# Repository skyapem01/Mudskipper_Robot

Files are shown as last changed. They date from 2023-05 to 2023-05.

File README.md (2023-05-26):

# Mudskipper_Robot
  หุ่นยนต์จำลองการเคลื่อนที่ของปลาตีน โดยจำลองตัวปลาตีน ครีบอก หาง 

## Mudskipper Robot Model
  การใช้งาน ในโฟลเดอร์ Mudskipper_Solid2022 มีไฟล์ Part และไฟล์ Assembly ซึ่งเป็น Model 3D ของตัวหุ่นยนต์ ไฟล์ให้งานกับ SolidWork ver.2022
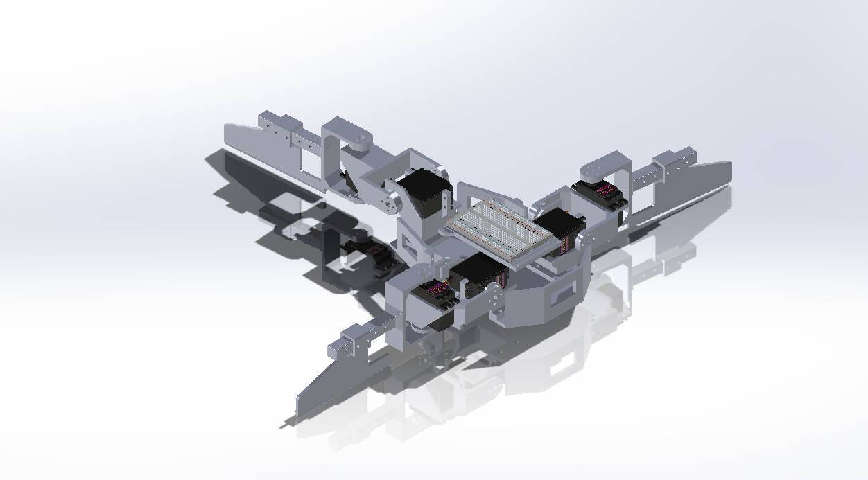
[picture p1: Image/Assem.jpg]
  

## Programing 
  ในโฟลเดอร์ Mudskipper_code มีไฟล์โปรแกรมการใช้งานหุ่นยนต์ โดยรวมโปรแกรมนี้ ใช้สมการ central pattern generators ในการสั่งงาน Servomoter ดังนั้นให้ศึกษา central pattern generators ก่อนทำความเข้าใจ code และใช้งาน code
  ### central pattern generators
  ประสาทชีวภาพที่จัดระเบียบตัวเองวงจรที่สร้างจังหวะเอาต์พุตในกรณีที่ไม่มีจังหวะป้อนข้อมูล. เป็นที่มาของรูปแบบของเส้นประสาทที่เชื่อมต่อกัน
 ที่ขับเคลื่อนจังหวะและพฤติกรรมของมอเตอร์ตายตัว
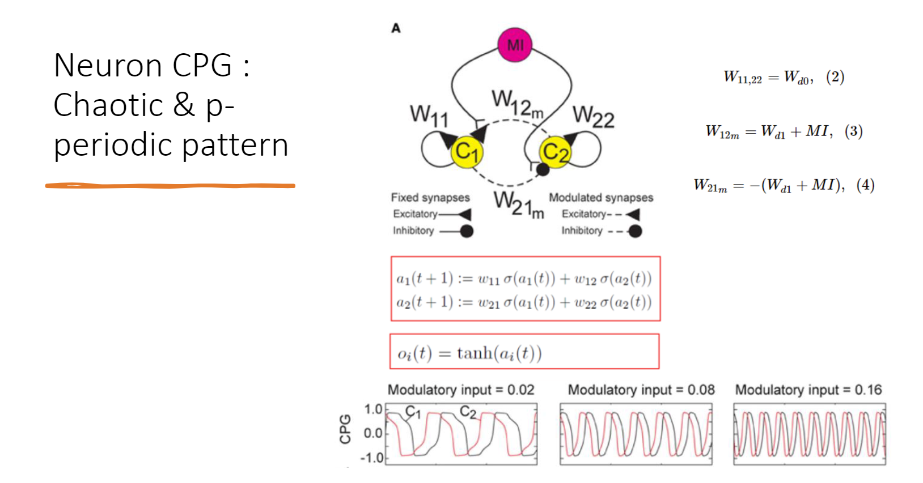
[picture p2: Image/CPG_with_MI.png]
  

 ## Document
  ในโฟลเดอร์ Mudskipper_Document มีไฟล์ Document อธิบายเกี่ยวกับ Mudskipper ทั้งหมด เช่น Circuit, Hardware , การทดลอง 
  ### Presenttation
  [Presentation](https://www.canva.com/design/DAFkBGQHBKI/dXqKwkPjZiT8uN1swqLo2Q/view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)

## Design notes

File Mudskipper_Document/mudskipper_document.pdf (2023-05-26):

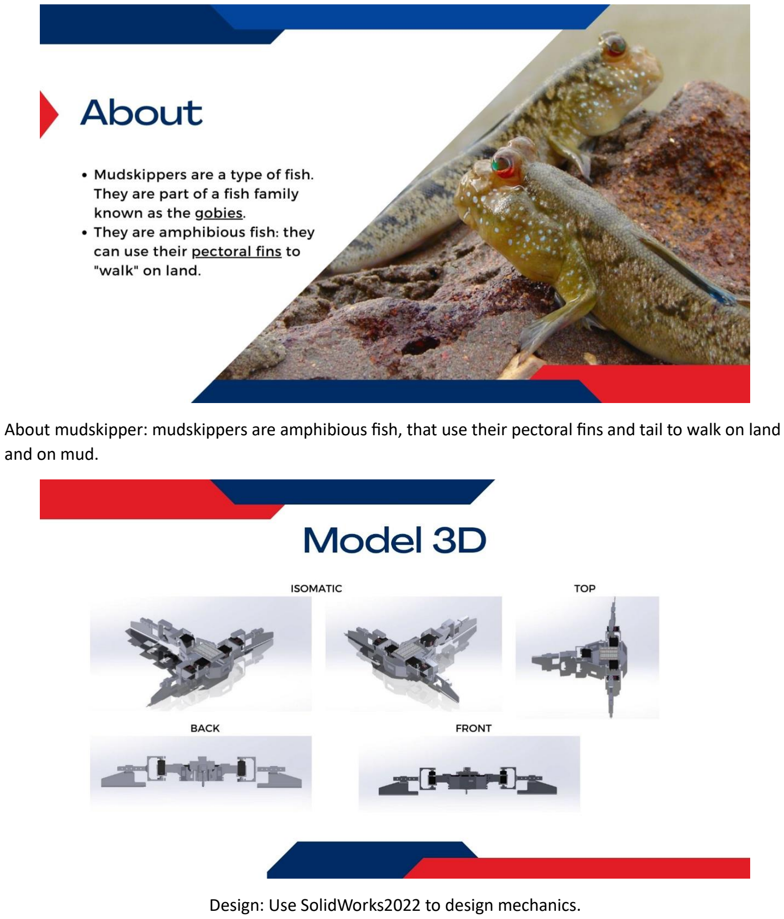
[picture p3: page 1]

About mudskipper: mudskippers are amphibious fish, that use their pectoral fins and tail to walk on land and on mud.

Design: Use SolidWorks2022 to design mechanics.

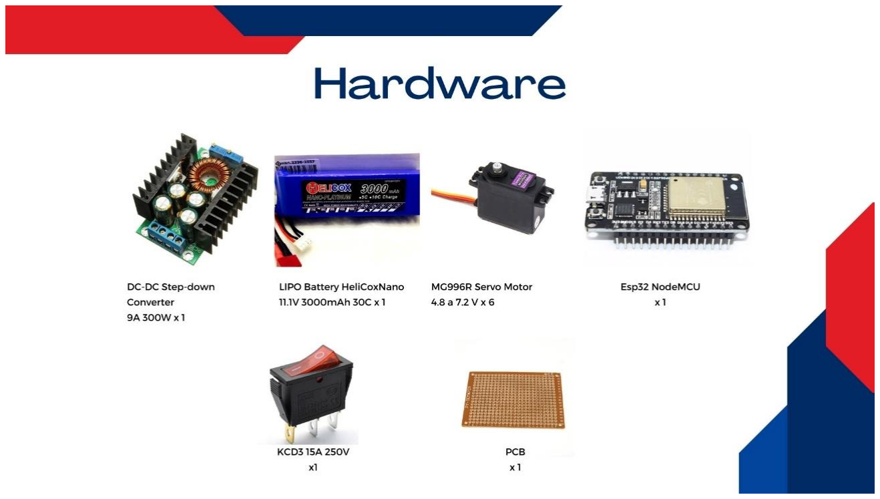
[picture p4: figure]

Hardware:

Part name | Qty.
LIPO Battery HeliCox Nano | 1
KCD3 Rocker Switch | 1
DC-DC Step Down Buck Converter | 1
ESP-WROOM-32 | 1
MG996R Servo motor | 6

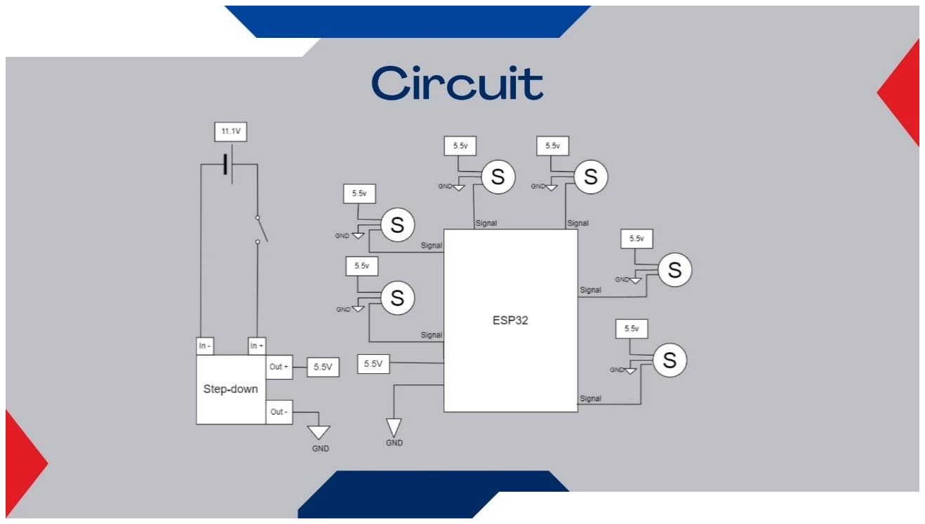
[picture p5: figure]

Circuit diagram: Power the ESP32 and servo motor with the LIPO Battery HeliCox Nano.

Step 1: As a circuit diagram, connect a switch to a LIPO Battery to power the ESP32 and servo motor.
Step 2: Use a DC-DC Step Down Buck Converter to reduce the current from the LIPO Battery HeliCox Nano to 7.2A and the voltage to 5.5V.
Step 3: Connect a signal and the GND of the servo motor to the ESP32, then connect to step 1 as shown.

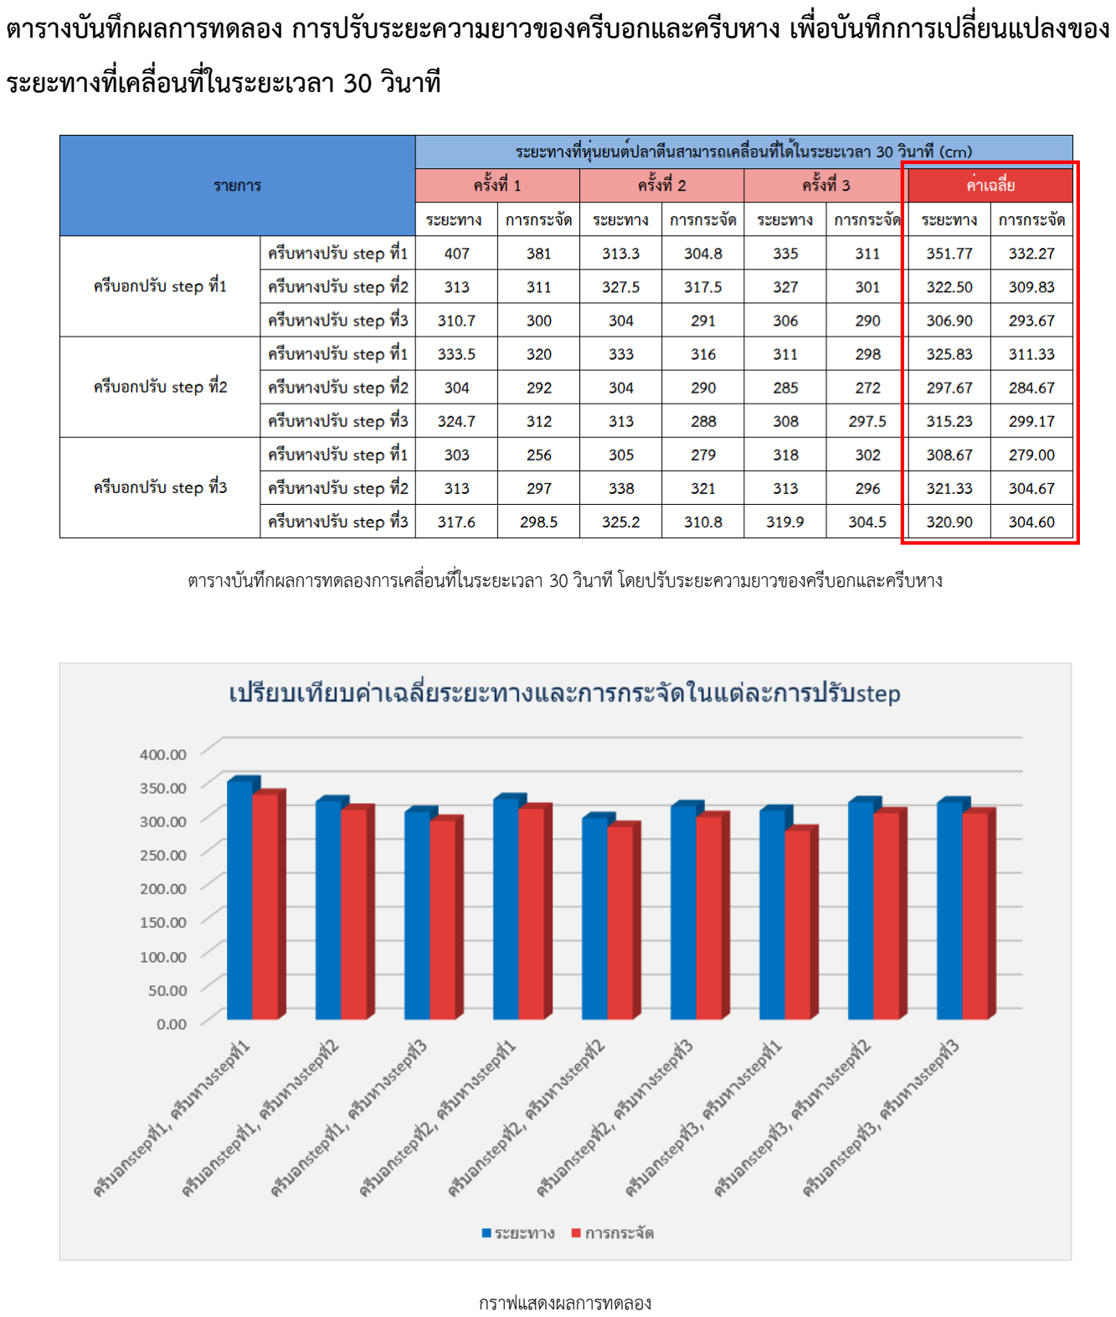
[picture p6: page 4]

ตารางบันทึกผลการทดลอง การปรับระยะความยาวของครีบอกและครีบหาง เพื่อบันทึกการเปลี่ยนแปลงของ ระยะทางที่เคลื่อนที่ในระยะเวลา 30 วินาที

ตารางบันทึกผลการทดลองการเคลื่อนที่ในระยะเวลา 30 วินาที โดยปรับระยะความยาวของครีบอกและครีบหาง

กราฟแสดงผลการทดลอง

อภิปรายผลการทดลอง

เมื่อครีบอกอยู่ระดับที่1:

ครีบหางระดับที่1 ระยะทางเฉลี่ยเท่ากับ 351.77 เซนติเมตร การกระจัดเฉลี่ยเท่ากับ 332.27 เซนติเมตร ครีบหางระดับที่2 ระยะทางเฉลี่ยเท่ากับ 322.50 เซนติเมตร การกระจัดเฉลี่ยเท่ากับ 309.83 เซนติเมตร ครีบหางระดับที่3 ระยะทางเฉลี่ยเท่ากับ 306.90 เซนติเมตร การกระจัดเฉลี่ยเท่ากับ 293.67 เซนติเมตร

เมื่อครีบอกอยู่ระดับที่2:

ครีบหางระดับที่1ระยะทางเฉลี่ยเท่ากับ 325.83 เซนติเมตร การกระจัดเฉลี่ยเท่ากับ 311.33 เซนติเมตร ครีบหางระดับที่2 ระยะทางเฉลี่ยเท่ากับ 297.67 เซนติเมตร การกระจัดเฉลี่ยเท่ากับ 284.67 เซนติเมตร ครีบหางระดับที่3 ระยะทางเฉลี่ยเท่ากับ 315.23 เซนติเมตร การกระจัดเฉลี่ยเท่ากับ 299.17 เซนติเมตร

เมื่อครีบอกอยู่ระดับที่3:

ครีบหางระดับที่1 ระยะทางเฉลี่ยเท่ากับ 308.67 เซนติเมตร การกระจัดเฉลี่ยเท่ากับ 279.00 เซนติเมตร ครีบหางระดับที่2 ระยะทางเฉลี่ยเท่ากับ 321.33 เซนติเมตร การกระจัดเฉลี่ยเท่ากับ 304.67 เซนติเมตร ครีบหางระดับที่3 ระยะทางเฉลี่ยเท่ากับ 320.90 เซนติเมตร การกระจัดเฉลี่ยเท่ากับ 304.60 เซนติเมตร

สรุปผลการทดลอง

จากข้อมูลข้างต้นแสดงให้เห็นว่าการปรับระยะความยาวของครีบอกและครีบหาง มีผลต่อระยะทางที่เคลื่อนที่ใน ระยะเวลา 30 วินาที โดยระยะทางที่เคลื่อนที่ได้จะมีค่าต่างกัน ตามการปรับระยะความยาวของครีบในแต่ละครั้ง และจากการ ทดลองสรุปผลได้ว่าในเวลาที่ 30 วินาทีเท่ากัน ระยะทางเฉลี่ยที่มากที่สุด คือ ครีบอกอยู่ระดับที่1 และครีบหางระดับที่1

ตารางบันทึกผลการทดลองการเปรียบเทียบลักษณะการเคลื่อนที่เข้าสู่จุดหมาย โดยการวัดค่า Displacement

แบ่งเป็น 4 การทดลอง

โดยการหาค่า Displacement Index อ้างอิงจากสูตร

สูตร

∆x คือ ระยะที่กำหนด

∆s คือ Pathway ที่หุ่นยนต์เดินทางได้

|| ∆r || = √x
2 + y

2

Displacement Index คือ ดัชนีวัดประสิทธิภาพในการเคลื่อนที่ของ หุ่นยนต์

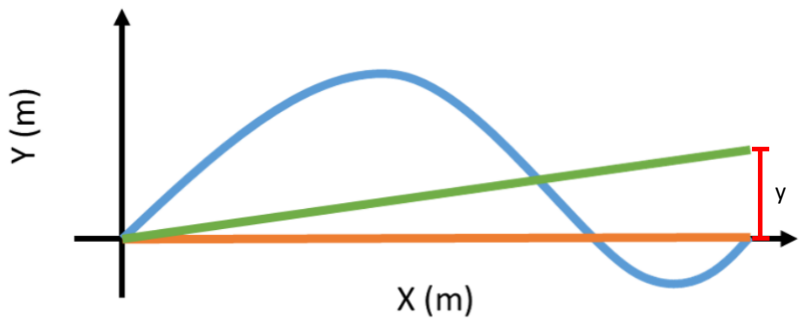
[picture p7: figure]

### 1. หาค่า displacement แบบเคลื่อนที่โดยไม่ใช้หาง ในระยะทางที่กำหนดเท่ากับ 100 cm

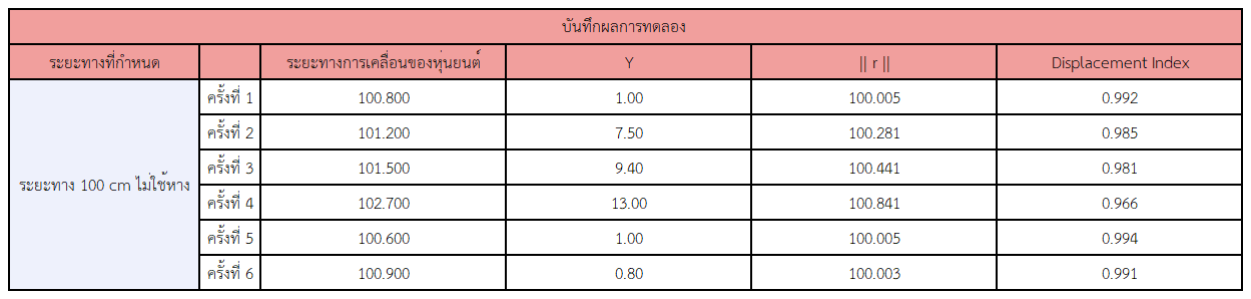
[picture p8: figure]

ตารางบันทึกผลการทดลองหาค่า displacement แบบเคลื่อนที่โดยไม่ใช้หาง และระยะทางที่กำหนดเท่ากับ 100 cm

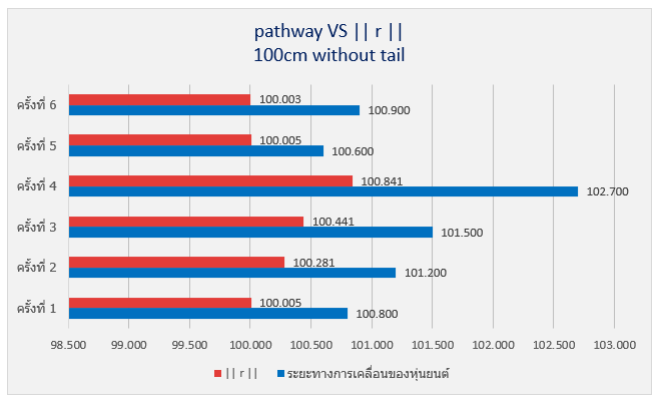
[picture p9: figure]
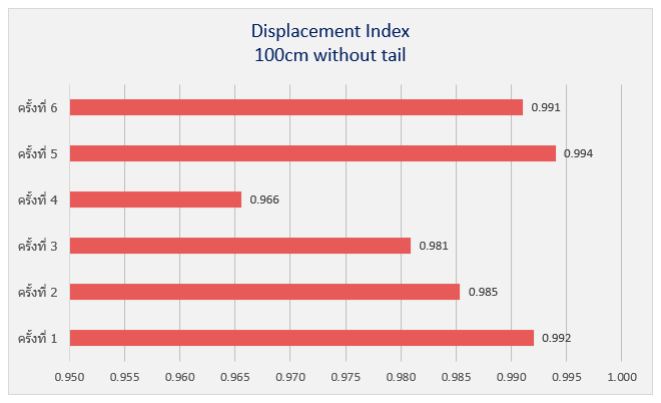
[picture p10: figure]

กราฟแสดงผล

อภิปรายผลการทดลอง : หาค่า displacement แบบเคลื่อนที่โดยไม่ใช้หาง ในระยะทางที่กำหนดเท่ากับ 100 cm

การทดลองครั้งที่ 1 : ระยะทางที่หุ่นยนต์เคลื่อนที่ = 100.80 cm, ค่า || r || = 100.005 cm, และค่า Displacement คือ 0.992

การทดลองครั้งที่ 2 : ระยะทางที่หุ่นยนต์เคลื่อนที่ = 101.20 cm, ค่า || r || = 100.218 cm, และค่า Displacement คือ 0.985

การทดลองครั้งที่ 3 : ระยะทางที่หุ่นยนต์เคลื่อนที่ = 101.50 cm, ค่า || r || = 100.441 cm, และค่า Displacement คือ 0.981

การทดลองครั้งที่ 4 : ระยะทางที่หุ่นยนต์เคลื่อนที่ = 102.70 cm, ค่า || r || = 100.841 cm, และค่า Displacement คือ 0.966

การทดลองครั้งที่ 5 : ระยะทางที่หุ่นยนต์เคลื่อนที่ = 100.60 cm, ค่า || r || = 100.005 cm, และค่า Displacement คือ 0.994

การทดลองครั้งที่ 6 : ระยะทางที่หุ่นยนต์เคลื่อนที่ = 100.90 cm, ค่า || r || = 100.003 cm, และค่า Displacement คือ 0.991

### 2. หาค่า displacement แบบเคลื่อนที่โดยใช้หาง และระยะทางที่กำหนดเท่ากับ 100 cm

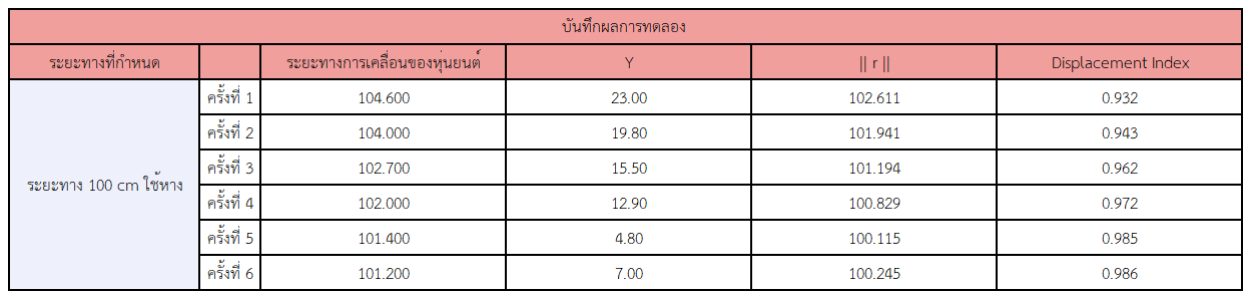
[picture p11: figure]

ตารางบันทึกผลการทดลองหาค่า displacement แบบเคลื่อนที่โดยใช้หาง และระยะทางที่กำหนดเท่ากับ 100 cm

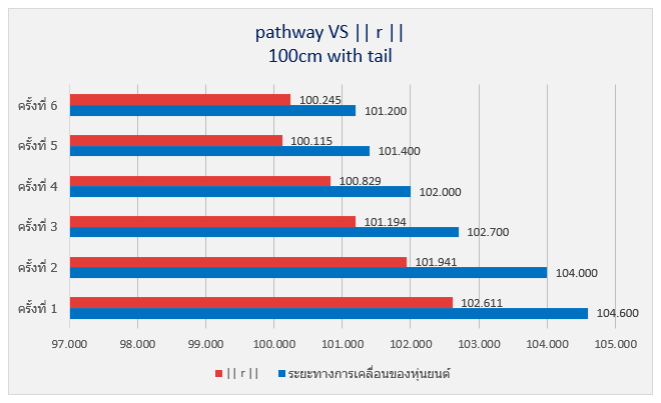
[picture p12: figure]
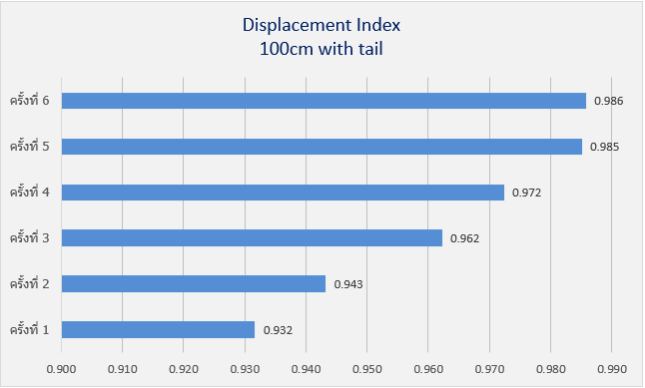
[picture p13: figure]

กราฟแสดงผล

อภิปรายผลการทดลอง : หาค่า displacement แบบเคลื่อนที่โดยใช้หาง ในระยะทางที่กำหนดเท่ากับ 100 cm

การทดลองครั้งที่ 1 : ระยะทางที่หุ่นยนต์เคลื่อนที่ = 104.60 cm, ค่า || r || = 102.611 cm, และค่า Displacement คือ 0.932

การทดลองครั้งที่ 2 : ระยะทางที่หุ่นยนต์เคลื่อนที่ = 104.00 cm, ค่า || r || = 101.941 cm, และค่า Displacement คือ 0.943

การทดลองครั้งที่ 3 : ระยะทางที่หุ่นยนต์เคลื่อนที่ = 102.70 cm, ค่า || r || = 101.194 cm, และค่า Displacement คือ 0.962

การทดลองครั้งที่ 4 : ระยะทางที่หุ่นยนต์เคลื่อนที่ = 102.00 cm, ค่า || r || = 100.829 cm, และค่า Displacement คือ 0.972

การทดลองครั้งที่ 5 : ระยะทางที่หุ่นยนต์เคลื่อนที่ = 101.40 cm, ค่า || r || = 100.115 cm, และค่า Displacement คือ 0.985

การทดลองครั้งที่ 6 : ระยะทางที่หุ่นยนต์เคลื่อนที่ = 101.20 cm, ค่า || r || = 100.245 cm, และค่า Displacement คือ 0.986

สรุปผลการทดลอง

จากการทดลองหาค่า displacement แบบเคลื่อนที่โดยใช้หาง ในระยะทาง 100 cm เห็นได้ว่าระยะทางที่หุ่นยนต์ เคลื่อนที่ (Pathway) และค่า || r || ที่คำนวณได้ในแต่ละครั้งของการทดลองมีค่าความห่างกันมากสุด 1.859 cm และค่า displacement คือ 0.966 ในขณะที่การทดลองที่มีค่าความห่างกันน้อยที่สุดประมาณ 0.595 cm และค่า displacement คือ 0.994

เมื่อเปรียบเทียบกับการทดลองหาค่า displacement แบบเคลื่อนที่โดยใช้หาง ในระยะทาง 100 cm เท่ากัน ระยะทางที่ หุ่นยนต์เคลื่อนที่ (Pathway) และค่า || r || ที่คำนวณได้ในแต่ละครั้งของการทดลองมีค่าความห่างกันมากสุด 2.059 cm และค่า displacement คือ 0.932 ในขณะที่การทดลองที่มีค่าความห่างกันน้อยที่สุดประมาณ 0.955 cm และค่า displacement คือ 0.986

### 3. หาค่า displacement แบบเคลื่อนที่โดยไม่ใช้หาง และระยะทางที่กำหนดเท่ากับ 200 cm

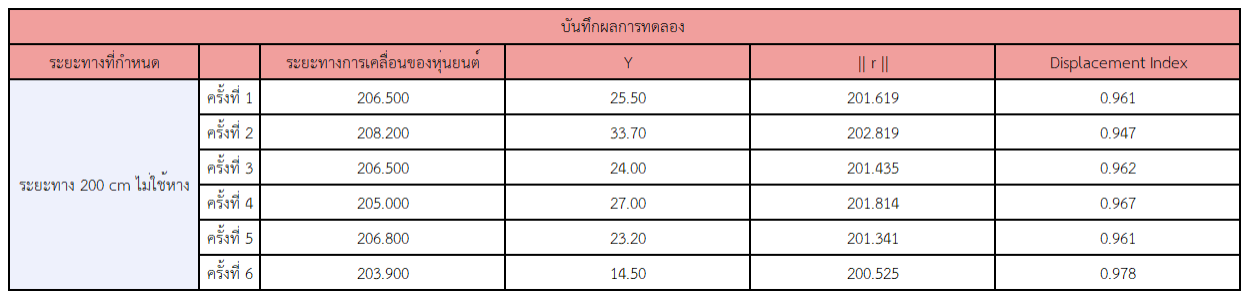
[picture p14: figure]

ตารางบันทึกผลการทดลองหาค่า displacement แบบเคลื่อนที่โดยไม่ใช้หาง และระยะทางที่กำหนดเท่ากับ 200 cm

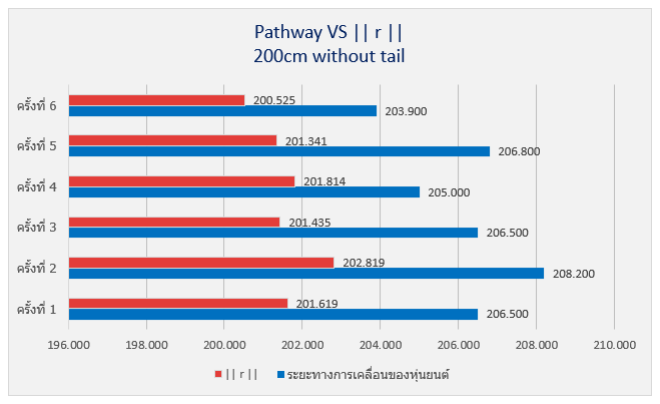
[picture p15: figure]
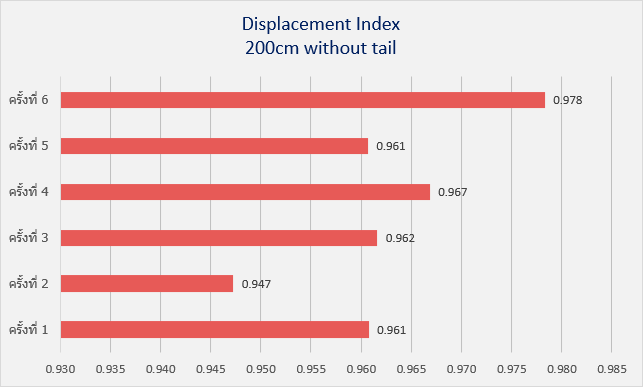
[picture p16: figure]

กราฟแสดงผล

อภิปรายผลการทดลอง : หาค่า displacement แบบเคลื่อนที่โดยไม่ใช้หาง ในระยะทางที่กำหนดเท่ากับ 200 cm

การทดลองครั้งที่ 1 : ระยะทางที่หุ่นยนต์เคลื่อนที่ = 206.50 cm, ค่า || r || = 201.619 cm, และค่า Displacement คือ 0.961

การทดลองครั้งที่ 2 : ระยะทางที่หุ่นยนต์เคลื่อนที่ = 208.20 cm, ค่า || r || = 202.819 cm, และค่า Displacement คือ 0.947

การทดลองครั้งที่ 3 : ระยะทางที่หุ่นยนต์เคลื่อนที่ = 206.50 cm, ค่า || r || = 201.435 cm, และค่า Displacement คือ 0.962

การทดลองครั้งที่ 4 : ระยะทางที่หุ่นยนต์เคลื่อนที่ = 205.00 cm, ค่า || r || = 201.814 cm, และค่า Displacement คือ 0.967

การทดลองครั้งที่ 5 : ระยะทางที่หุ่นยนต์เคลื่อนที่ = 206.80 cm, ค่า || r || = 201.341 cm, และค่า Displacement คือ 0.961

การทดลองครั้งที่ 6 : ระยะทางที่หุ่นยนต์เคลื่อนที่ = 203.90 cm, ค่า || r || = 200.525 cm, และค่า Displacement คือ 0.978

### 4. หาค่า displacement แบบเคลื่อนที่โดยใช้หาง และระยะทางที่กำหนดเท่ากับ 200 cm

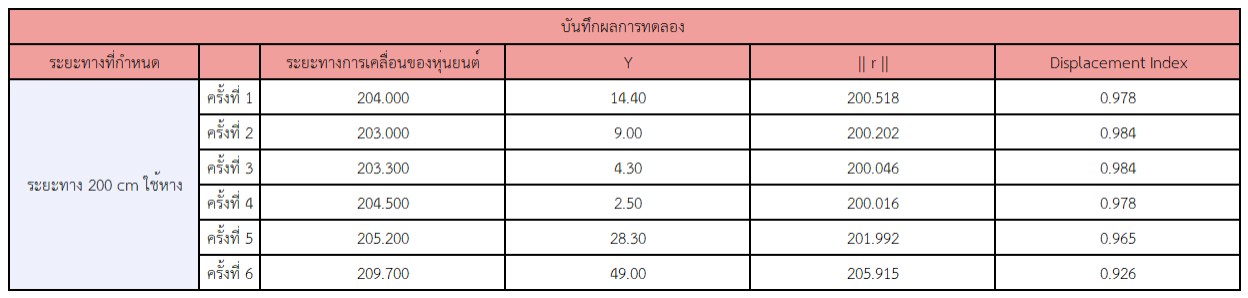
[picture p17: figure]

ตารางบันทึกผลการทดลองหาค่า displacement แบบเคลื่อนที่โดยใช้หาง และระยะทางที่กำหนดเท่ากับ 200 cm

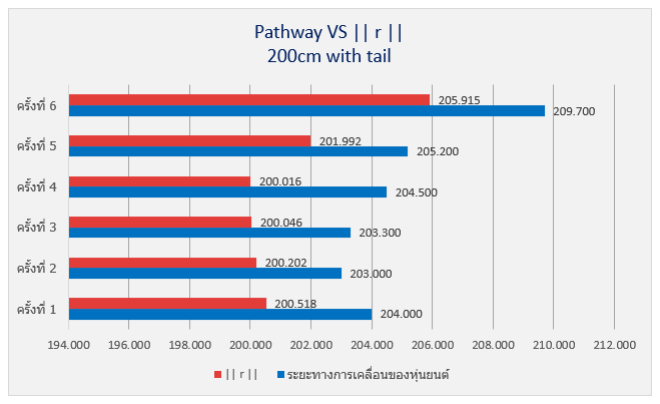
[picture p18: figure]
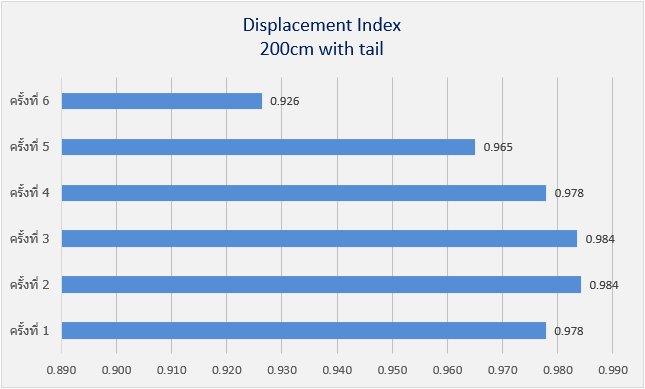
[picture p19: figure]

กราฟแสดงผล

อภิปรายผลการทดลอง : หาค่า displacement แบบเคลื่อนที่โดยใช้หาง ในระยะทางที่กำหนดเท่ากับ 200 cm

การทดลองครั้งที่ 1 : ระยะทางที่หุ่นยนต์เคลื่อนที่ = 204.00 cm, ค่า || r || = 200.518 cm, และค่า Displacement คือ 0.978

การทดลองครั้งที่ 2 : ระยะทางที่หุ่นยนต์เคลื่อนที่ = 203.00 cm, ค่า || r || = 200.202 cm, และค่า Displacement คือ 0.984

การทดลองครั้งที่ 3 : ระยะทางที่หุ่นยนต์เคลื่อนที่ = 203.30 cm, ค่า || r || = 200.046 cm, และค่า Displacement คือ 0.984

การทดลองครั้งที่ 4 : ระยะทางที่หุ่นยนต์เคลื่อนที่ = 204.50 cm, ค่า || r || = 200.016 cm, และค่า Displacement คือ 0.978

การทดลองครั้งที่ 5 : ระยะทางที่หุ่นยนต์เคลื่อนที่ = 205.20 cm, ค่า || r || = 201.992 cm, และค่า Displacement คือ 0.965

การทดลองครั้งที่ 6 : ระยะทางที่หุ่นยนต์เคลื่อนที่ = 209.70 cm, ค่า || r || = 205.915 cm, และค่า Displacement คือ 0.926

สรุปผลการทดลอง

จากการทดลองหาค่า displacement แบบเคลื่อนที่โดยไม่ใช้หาง ในระยะทาง 200 cm เห็นได้ว่าระยะทางที่หุ่นยนต์ เคลื่อนที่ (Pathway) และค่า || r || ที่คำนวณได้ในแต่ละครั้งของการทดลองมีค่าความห่างกันมากสุด 1.859 cm และค่า displacement คือ 0.966 ในขณะที่การทดลองที่มีค่าความห่างกันน้อยที่สุดประมาณ 0.595 cm และค่า displacement คือ 0.994

เมื่อเปรียบเทียบกับการทดลองหาค่า displacement แบบเคลื่อนที่โดยใช้หาง ในระยะทาง 200 cm เท่ากัน ระยะทางที่ หุ่นยนต์เคลื่อนที่ (Pathway) และค่า || r || ที่คำนวณได้ในแต่ละครั้งของการทดลองมีค่าความห่างกันมากสุด 3.785 cm และค่า displacement คือ 0.926 ในขณะที่การทดลองที่มีค่าความห่างกันน้อยที่สุดประมาณ 2.798 cm และค่า displacement คือ 0.984

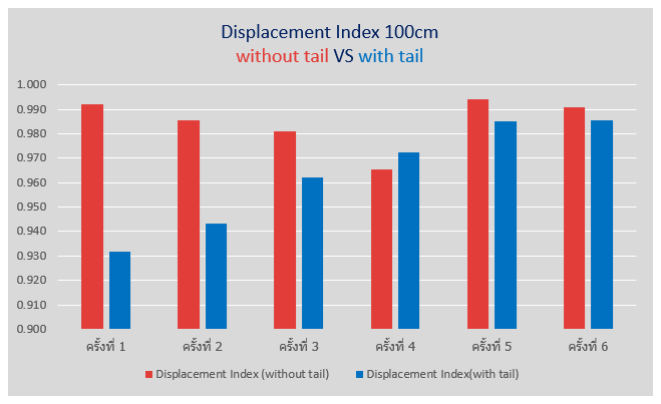
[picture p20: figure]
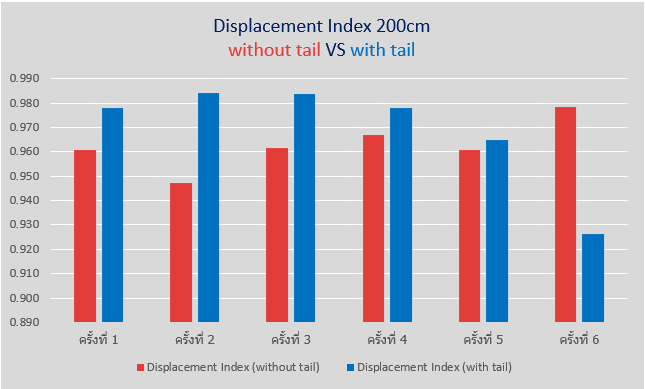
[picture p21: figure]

กราฟเปรียบเทียบค่า displacement ระหว่างใช้หางและไม่ใช้หางในระยะ 100 cm และ 200 cm

จากกราฟ การเปรียบเทียบ Displacement Index ของการเคลื่อนที่ 100 cm การเคลื่อนที่ไม่ใช้หางมีค่า Displacement Index ที่ดีกว่าการเคลื่อนที่ที่ใช้หางช่วย ในการกราฟการเทียบเทียบ Displacement Index ของการเคลื่อนที่ 200 cm การเคลื่อนที่ที่ใช้หางช่วยมีค่า Displacement Index ที่ดีกว่าการเคลื่อนที่ที่ไม่ใช้หาง

ปัญหาที่พบ :

การเปลี่ยนระดับครีบหางและครีบอก

จากผลการสรุปการทดลองการเปลี่ยนระดับครีบหางและครีบอก ตามทฤษฎีแล้ว ถ้าเพิ่มระยะของครีบอกหรือครีบหาง จะทำให้ระยะการเคลื่อนเพิ่มขึ้น เนื่องจากพื้นที่หน้าสัมผัสกับพื้นมากขึ้น แต่จากการทดลองไม่เป็นไปตามทฤษฎีอาจเป็นเพราะมี ปัจจัยอื่นมาเกี่ยวข้องในการเคลื่อนที่ เช่น พื้นผิวในการทดสอบ, สมดุลของหุ่นขณะเคลื่อนที่เมื่อขยายครีบ, แรงกระแทกกับพื้นเมื่อ หุ่นเคลื่อนที่ ทำให้ทิศทางการเคลื่อนที่เปลี่ยนแปลงจากเดิม

การวัดค่า Displacement

จากการทดลองการวัดค่า Displacement ในระยะ 100 cm และ 200 cm วิธีการบันทึกระยะทางการเคลื่อนที่ของ หุ่นยนต์ไม่เสถียร

ข้อเสนอแนะ :

การเปลี่ยนระดับครีบหางและครีบอก

1.ควรเพิ่มตัวแปรควบคุมในการทดลอง เช่น ชนิดพื้นผิวในการทดลองให้มีความหลากหลายมากขึ้น

2.ควรทดลองเปลี่ยนวัสดุที่ทำครีบเพื่อการเคลื่อนที่ที่ดีขึ้น โดยมีแรงบันดาลจากปลาตีนมากขึ้นอีก

3.เพิ่มเซ็นเซอร์ในการรับรู้สภาพแวดล้อม เพื่อให้การเคลื่อนที่มีประสิทธิภาพมากขึ้น

การวัดค่า Displacement

1.ควรมีวิธีการในการบันทึกการเคลื่อนที่ของหุ่นยนต์ที่ไม่ส่งผลต่อการเคลื่อนที่ของหุ่นยนต์เอง

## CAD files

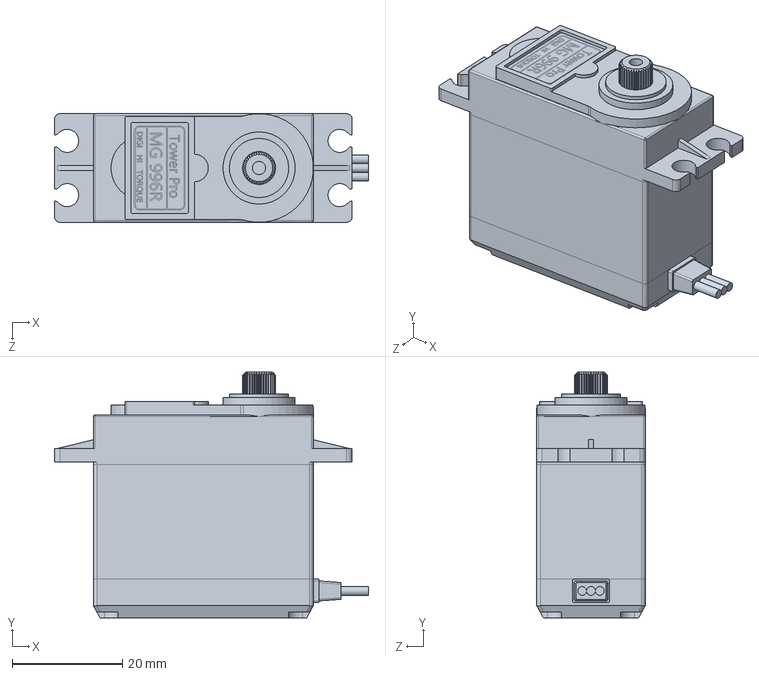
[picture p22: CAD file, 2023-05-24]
Mudskipper_Solid2022/Mudskipper_Solid2022/Servo Motor MG996R With Attachments.SLDASM
57.0 x 44.5 x 19.7 mm

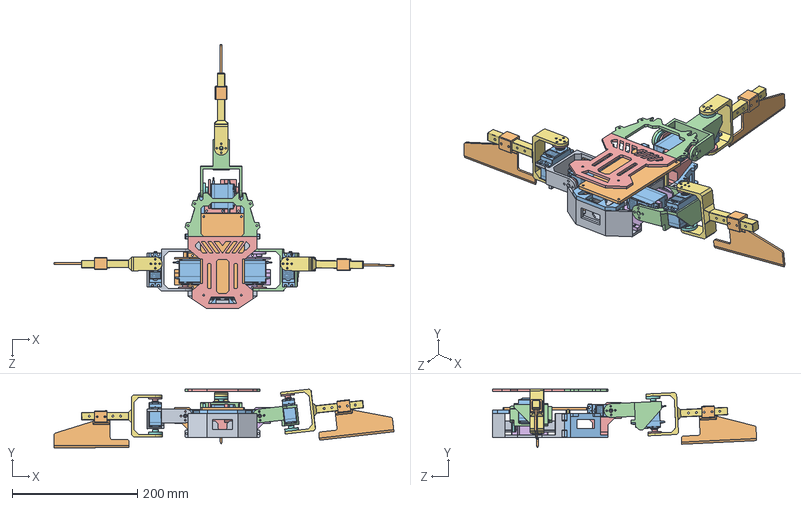
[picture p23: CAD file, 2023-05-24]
Mudskipper_Solid2022/Mudskipper_Solid2022/Assem4.SLDASM
542.7 x 93.9 x 421.9 mm
Plate_final
Plate_Right
Servo Motor MG996R x 6
ติดก้าน
circleServo_6m x 6
circle_7m
ติดก้านหาง - Copy x 3
circle_6m x 4
ติดก้าน - Copy (2)
Foot x 3
Plate_Back1
ติดก้านหาง
Plate_1Back
Plate_Left
Stud_41m x 2
Stud_41m - Copy x 2
Batterry_Base
switch

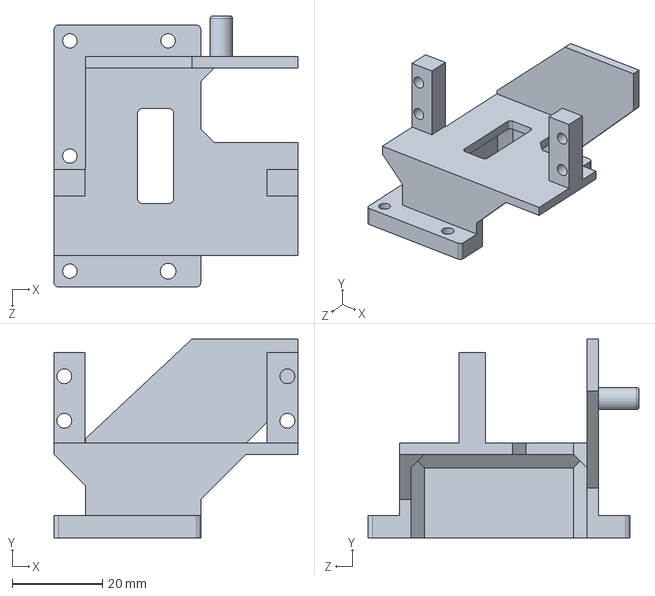
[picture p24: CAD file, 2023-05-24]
Mudskipper_Solid2022/Mudskipper_Solid2022/Plate_Left.SLDPRT
54.0 x 44.0 x 60.0 mm

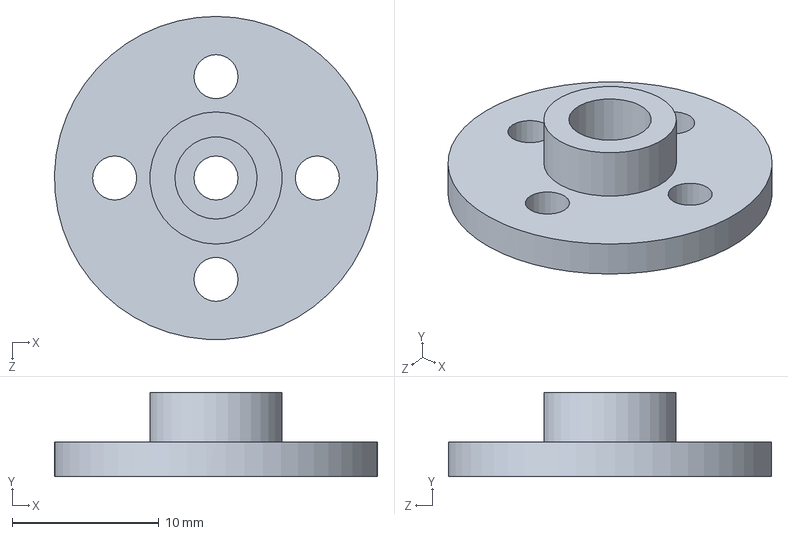
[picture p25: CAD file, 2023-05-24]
Mudskipper_Solid2022/Mudskipper_Solid2022/circleServo_6m.SLDPRT
22.0 x 5.75 x 22.0 mm

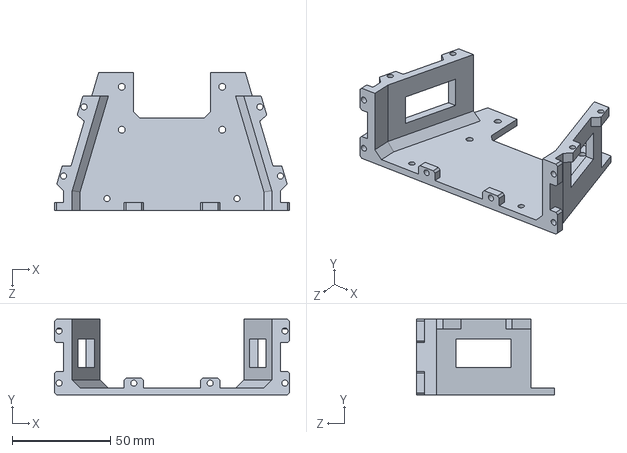
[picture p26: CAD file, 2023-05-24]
Mudskipper_Solid2022/Mudskipper_Solid2022/Plate_Back1.SLDPRT
119.3 x 38.5 x 70.0 mm

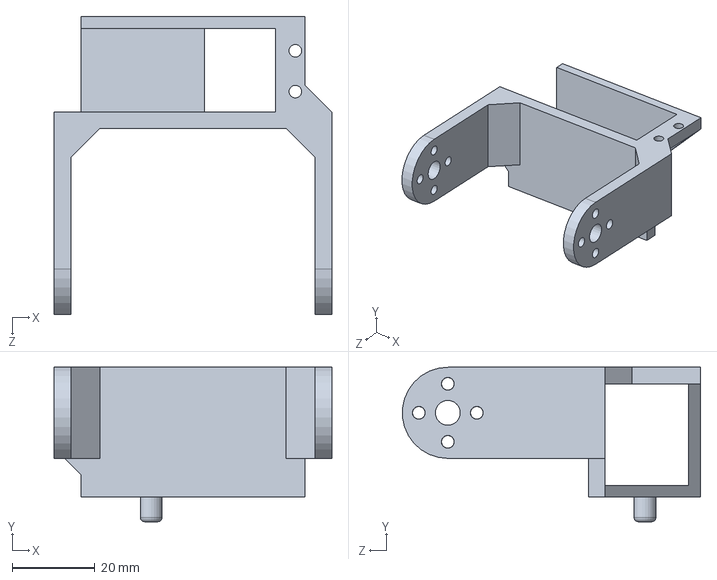
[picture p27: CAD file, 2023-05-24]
Mudskipper_Solid2022/Mudskipper_Solid2022/Servo_Left.SLDPRT
67.0 x 37.3 x 71.9 mm

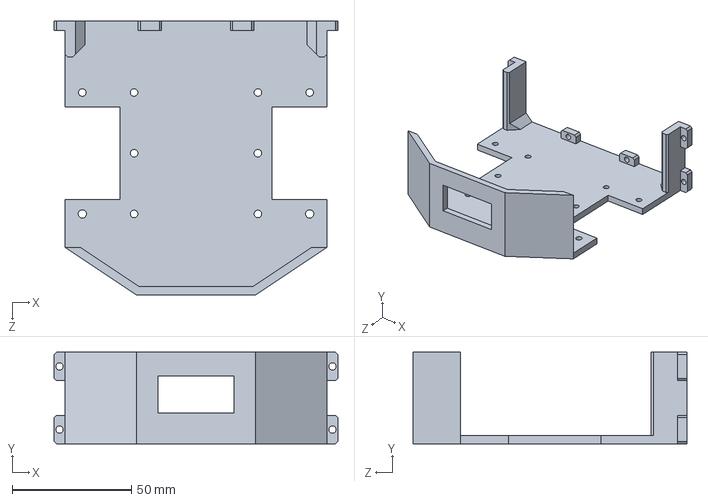
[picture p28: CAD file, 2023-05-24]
Mudskipper_Solid2022/Mudskipper_Solid2022/Plate_final.SLDPRT
119.3 x 38.5 x 115.0 mm

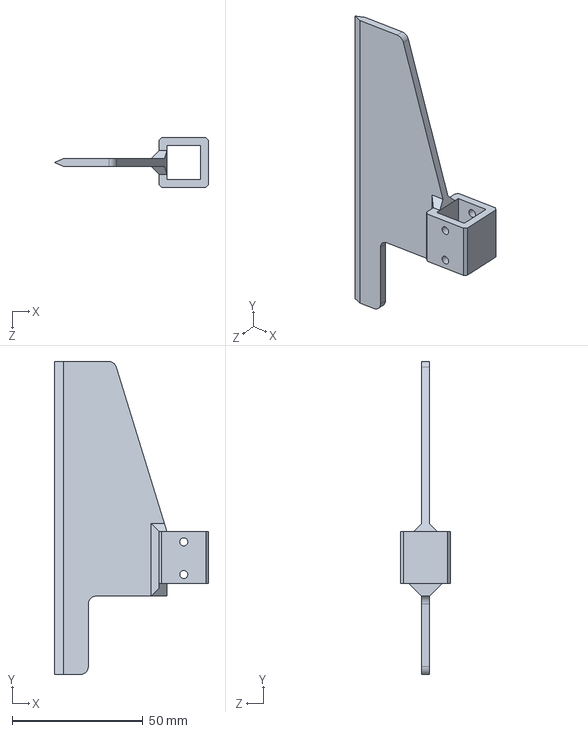
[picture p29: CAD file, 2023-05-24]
Mudskipper_Solid2022/Mudskipper_Solid2022/Foot.SLDPRT
59.0 x 119.7 x 19.0 mm

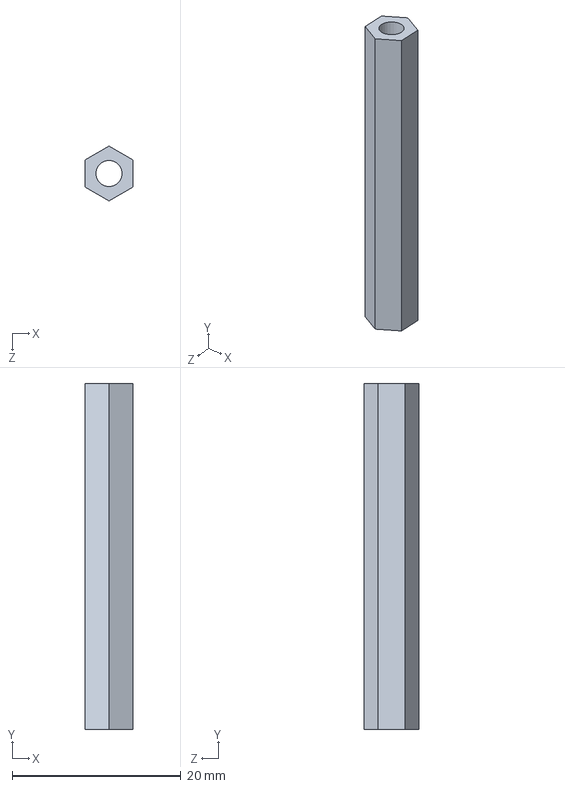
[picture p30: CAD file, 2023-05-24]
Mudskipper_Solid2022/Mudskipper_Solid2022/Stud_41m.SLDPRT
5.63 x 41.0 x 6.50 mm

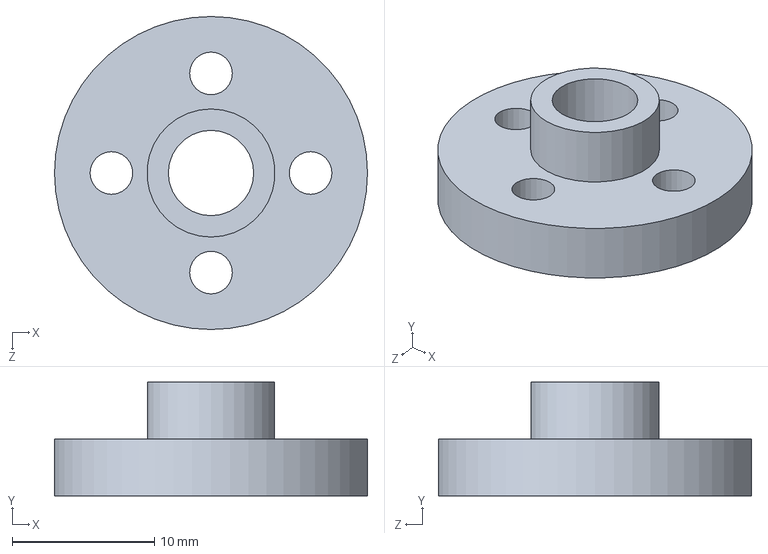
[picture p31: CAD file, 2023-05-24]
Mudskipper_Solid2022/Mudskipper_Solid2022/circle_6m.SLDPRT
22.0 x 8.00 x 22.0 mm

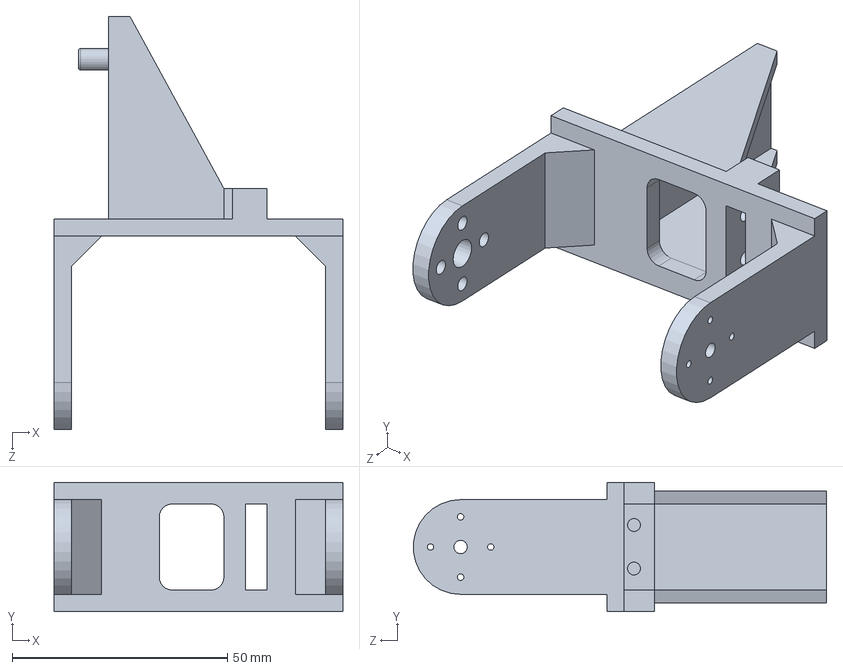
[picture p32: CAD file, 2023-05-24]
Mudskipper_Solid2022/Mudskipper_Solid2022/Servo_Back.SLDPRT
67.0 x 30.0 x 95.9 mm

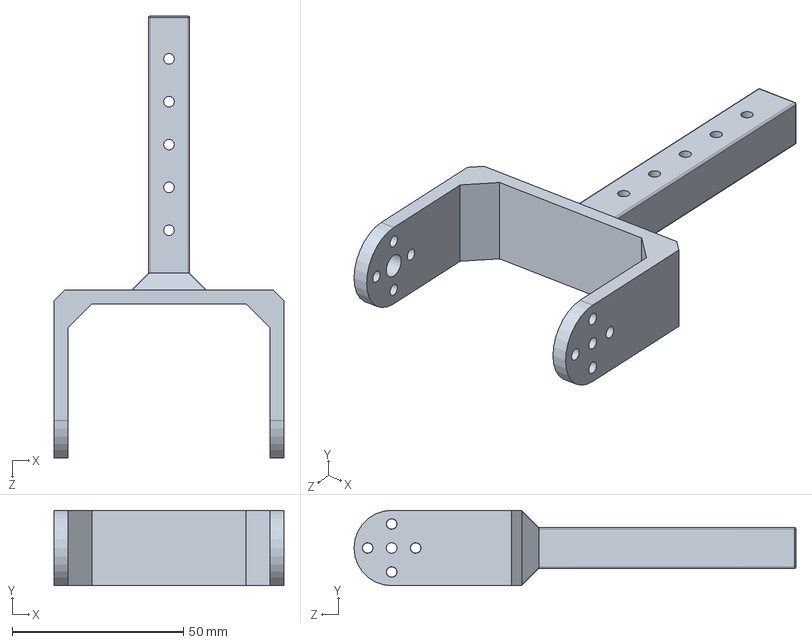
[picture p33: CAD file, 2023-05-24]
Mudskipper_Solid2022/Mudskipper_Solid2022/ติดก้านหาง - Copy.SLDPRT
67.0 x 22.0 x 128.9 mm

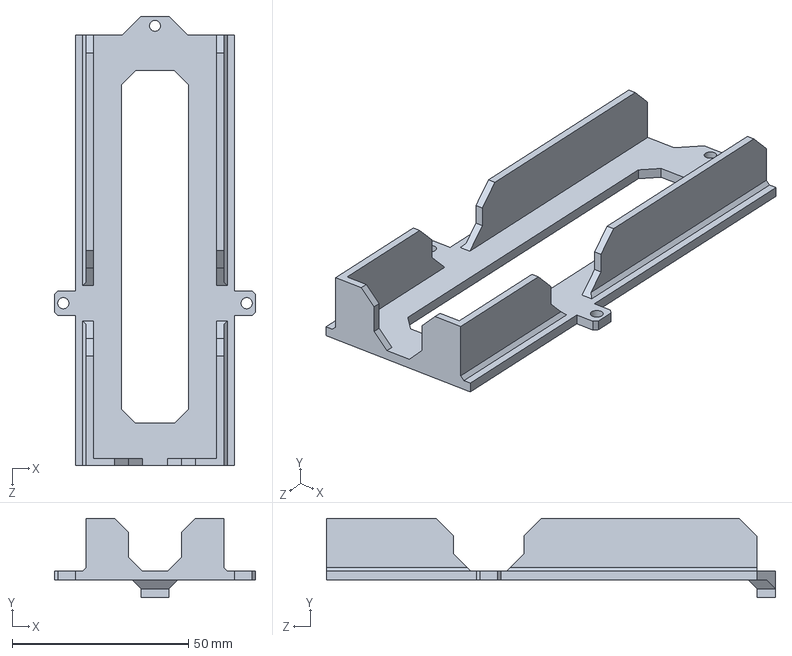
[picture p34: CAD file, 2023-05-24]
Mudskipper_Solid2022/Mudskipper_Solid2022/Batterry_Base.SLDPRT
57.0 x 22.5 x 127.3 mm

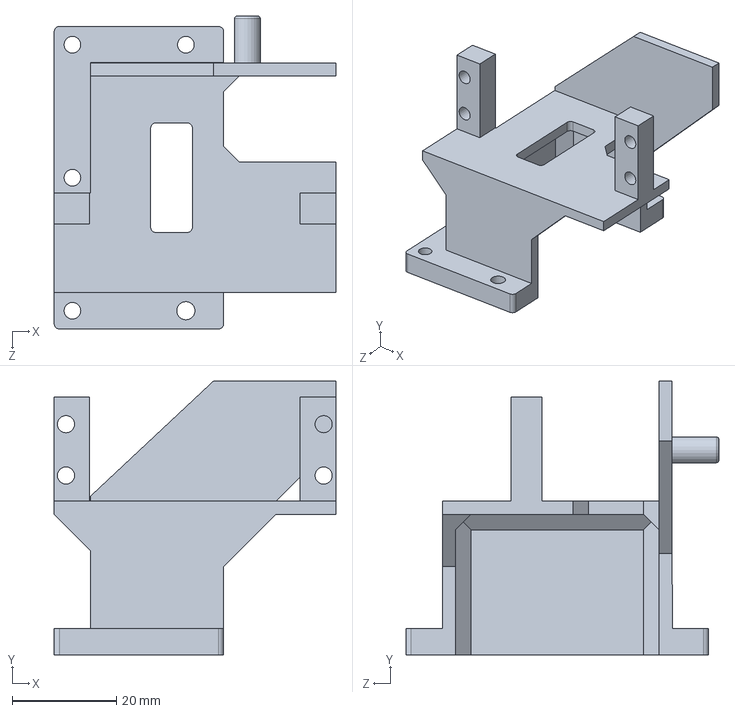
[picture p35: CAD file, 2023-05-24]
Mudskipper_Solid2022/Mudskipper_Solid2022/Plate_1Back.SLDPRT
54.0 x 52.4 x 60.0 mm

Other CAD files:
Mudskipper_Solid2022/Mudskipper_Solid2022/Servo_Right.SLDPRT
Mudskipper_Solid2022/Mudskipper_Solid2022/circle_7m.SLDPRT
Mudskipper_Solid2022/Mudskipper_Solid2022/Plate_Right.SLDPRT
Mudskipper_Solid2022/Mudskipper_Solid2022/Stud_41m - Copy.SLDPRT

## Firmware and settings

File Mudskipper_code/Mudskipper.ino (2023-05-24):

#include "Arduino.h"
#include <ESP32Servo.h>

#define _DEBUG_SERIAL

///define Servo 6 join 
Servo servoleft1; 
Servo servoleft2;
Servo servoright1;
Servo servoright2;
Servo tail1;
Servo tail2;

/// define var CPG 1st
double alpha,MI,Pi,Phi  ;
double W_1,W_2,W_3,W_4,W_13,W_24,W_35,W_46 ;
double B_1,B_2 ;
double H_1,H_2,H_3,H_4,H_5,H_6 ;
double O_1,O_2,O_3,O_4,O_5,O_6 ;
double use_cpg_1,use_cpg_2,use_cpg_3,use_cpg_4,use_cpg_5,use_cpg_6 ;


/// define var CPG 2nd
double alpha_2,MI_2,Phi_2;
double W_11,W_22,W_33,W_44,W_1133,W_2244 ;
double H_11,H_22,H_33,H_44 ;
double O_11,O_22,O_33,O_44 ;
double B_11,B_22 ;
double use_cpg2_1,use_cpg2_2,use_cpg2_3,use_cpg2_4 ;

/// define var command servo
double use_servo_1,use_servo_2,use_servo_3,use_servo_4,use_servo_5,use_servo_6 ;

//setting timer
long Time;
unsigned long prevTime = 0;  // global variable
unsigned long interval = 75; // 50 ms

void setup() {
  // put your setup code here, to run once:
  Serial.begin(115200);
  /// define var CPG 1st
  alpha = 1.15 ; 
  MI = 0.05;
  Pi = 3.14 ;
  Phi = (Pi/8) ;
  B_1 = 0 ;
  B_2 = 0 ;
  H_1 = 0.5 ;
  H_2 = 0.5 ;
  H_3 = 0.5 ;
  H_4 = 0.5 ;
  H_5 = 0.5 ;
  H_6 = 0.5 ;
  O_1 = tanh(H_1) ;
  O_2 = tanh(H_2) ;
  O_3 = tanh(H_3) ;
  O_4 = tanh(H_4) ;
  O_5 = tanh(H_5) ;
  O_6 = tanh(H_6) ;
  W_1 = cos(Phi)*alpha ;
  W_2 = cos(Phi)*alpha ;
  W_3 = (sin(Phi)*alpha) + MI ; 
  W_4 = -((sin(Phi)*alpha) + MI) ;
  W_13 = 0.5 ;
  W_24 = 0.5 ;
  W_35 = 0.5 ;
  W_46 = 0.5 ;


  //// /// define var CPG 2nd
  alpha_2 = 1.15 ;
  MI_2 = 0.05;
  Phi_2 = (3.14/16) ;
  H_11 = 0.5 ;
  H_22 = 0.5 ;
  H_33 = 0.5 ;
  H_44 = 0.5 ;
  O_11 = tanh(H_11) ;
  O_22 = tanh(H_22) ;
  O_33 = tanh(H_33) ;
  O_44 = tanh(H_44) ;
  W_11 = cos(Phi_2)*alpha ;
  W_22 = cos(Phi_2)*alpha ;
  W_33 = (sin(Phi_2)*alpha) + MI_2 ; 
  W_44 = -((sin(Phi_2)*alpha) + MI_2) ;
  B_11 = 0 ;
  B_22 = 0 ;
  W_1133 = 0.5 ;
  W_2244 = 0.5 ;

  /// setting servo
  servoleft1.attach(12); //รู11 
  servoleft1.write(90);  //135องศา-ขึ้น
  servoleft2.attach(14); //รู12 
  servoleft2.write(45);  //90องศา-ไปหลัง

  servoright1.attach(26); //14 
  servoright1.write(50);  //0องศา-ขึ้น  
  servoright2.attach(25); //15 
  servoright2.write(90);  //45องศา-ไปหลัง
  

  tail1.attach(15);  //รู8ขวาบอร์ด
  tail1.write(86);  //ขึ้น135
  tail2.attach(2);  //รู9ขวาบอร์ด
  tail2.write(90);  //180ปัดซ้าย
  
  delay(3000) ; //wait 3 sec

}
  //// function mapping arduino
  double mapf(double val, double in_min, double in_max, double out_min, double out_max) {
    return (val - in_min) * (out_max - out_min) / (in_max - in_min) + out_min;
}

void loop() {
  
  unsigned long currentTime = millis(); //set currentTime
  
  if(currentTime - prevTime >= interval){
    prevTime = currentTime;  
    
    //// start CPG 1st equation
    H_1 = (W_1*O_1)+(W_4*O_2)+B_1 ;
    H_2 = (W_2*O_2)+(W_3*O_1)+B_2 ;
    O_1 = tanh(H_1) ;
    O_2 = tanh(H_2) ;
    
    H_3 = (W_13*O_3)+O_1 ;
    H_4 = (W_24*O_4)+O_2 ;
    O_3 = tanh(H_3) ;
    O_4 = tanh(H_4) ;  
    
    H_5 = (W_35*O_5)+O_3 ;
    H_6 = (W_46*O_6)+O_4 ;
    O_5 = tanh(H_5) ;
    O_6 = tanh(H_6) ;    
    
    use_cpg_1 = O_1   ;
    use_cpg_2 = O_2  ;
    use_cpg_3 = O_3  ;
    use_cpg_4 = O_4  ;
    use_cpg_5 = O_5  ;
    use_cpg_6 = O_6  ;

    //// start CPG 1st equation
    H_11 = (W_11*O_11)+(W_44*O_22)+B_11 ;
    H_22 = (W_22*O_22)+(W_33*O_11)+B_22 ;
    O_11 = tanh(H_11) ;
    O_22 = tanh(H_22) ;

    use_cpg2_1 = O_11  ;
    use_cpg2_2 = O_22 ;  

    H_33 = (W_1133*O_3)+O_1 ;
    H_44 = (W_24*O_4)+O_2 ;
    O_33 = tanh(H_3) ;
    O_44 = tanh(H_4) ; 

    use_cpg2_3 = O_33  ;
    use_cpg2_4 = O_44 ; 


  use_servo_1 = mapf(use_cpg_1, -1.0, 1.0, 10.0, 170.0);  // front-back /// mapping tanh to angle servo
  use_servo_2 = mapf(use_cpg_2, -1.0, 1.0, 55.0, 135.0);  // down-top /// mapping tanh to angle servo
  
  #ifdef _DEBUG_SERIAL
  Serial.print("-------------------servo1 = ");
  Serial.println(use_servo_1); 
  Serial.print("-------------------servo2 = ");
  Serial.println(use_servo_2);
  #endif
  
  servoleft1.write(use_servo_2);  /// motor running following tanh
  servoleft2.write(use_servo_1);  /// motor running following tanh
  
  use_servo_3 = mapf(use_cpg_1, -1.0, 1.0, 130.0, -20.0); // front-back /// mapping tanh to angle servo
  use_servo_4 = mapf(use_cpg_2, -1.0, 1.0, 88.0, 0.0); // down-top /// mapping tanh to angle servo
  #ifdef _DEBUG_SERIAL
  Serial.print("-------------------servo3 = ");
  Serial.println(use_servo_3); 
  Serial.print("-------------------servo4 = ");
  Serial.println(use_servo_4);
  #endif
  
  servoright1.write(use_servo_4);  /// motor running following tanh
  servoright2.write(use_servo_3);  /// motor running following tanh

  use_servo_5 = mapf(use_cpg2_1, -1.0, 1.0, 180.0, 0.0); // left-right /// mapping tanh to angle servo
  use_servo_6 = mapf(use_cpg2_4, -1.0, 1.0, 75.0, 130.0); // down-top /// mapping tanh to angle servo

  #ifdef _DEBUG_SERIAL
  Serial.print("-------------------servo5 = ");
  Serial.println(use_servo_5);
  Serial.print("-------------------servo6 = ");
  Serial.println(use_servo_6);
  #endif
  
  tail1.write(use_servo_6);   /// motor running following tanh
   tail2.write(use_servo_5);  /// motor running following tanh
  
  
  #ifdef _DEBUG_SERIAL  
  Serial.print("H1 = ");
  Serial.println(H_1);
  Serial.print("H2 = ");
  Serial.println(H_2);
  Serial.print("O1 = ");
  Serial.println(O_1); 
  Serial.print("O2 = ");
  Serial.println(O_2);
  Serial.print("O3 = ");
  Serial.println(O_3); 
  Serial.print("O4 = ");
  Serial.println(O_4);
  Serial.print("O5 = ");
  Serial.println(O_6); 
  Serial.print("O6 = ");
  Serial.println(O_6);
  #endif
  }

  
}



  
